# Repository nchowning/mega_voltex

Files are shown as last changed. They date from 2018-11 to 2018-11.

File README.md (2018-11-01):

# MEGA Voltex
An Arduino Mega 2560 Sound Voltex controller shield for use with [ACreal_IO](https://github.com/Nadeflore/ACreal_IO).

This is still SUPER early days. The plan is to solder components to this shield, desolder the USB connector & power connector from an Arduino Mega 2560, slap this bad boy on top of it, and design a 3D printed enclosure for it.

# Credit
- [mon's PocketVoltex](https://github.com/mon/PocketVoltex) - Rotary encoder footprint & model. mon has a ton of amazing projects and is a super nice guy!
- [kcswalter's Electronic CAD libraries](http://smisioto.no-ip.org/elettronica/kicad/kicad-en.htm) - Arduino Mega header. Lots of useful libraries, footprints, & models here!
- [KiCad's footprints](https://github.com/KiCad/kicad-footprints) - I modified a couple of their SW_Cherry MX1A footprints to add LED through-holes. I plan on submitting a PR upstream for this.

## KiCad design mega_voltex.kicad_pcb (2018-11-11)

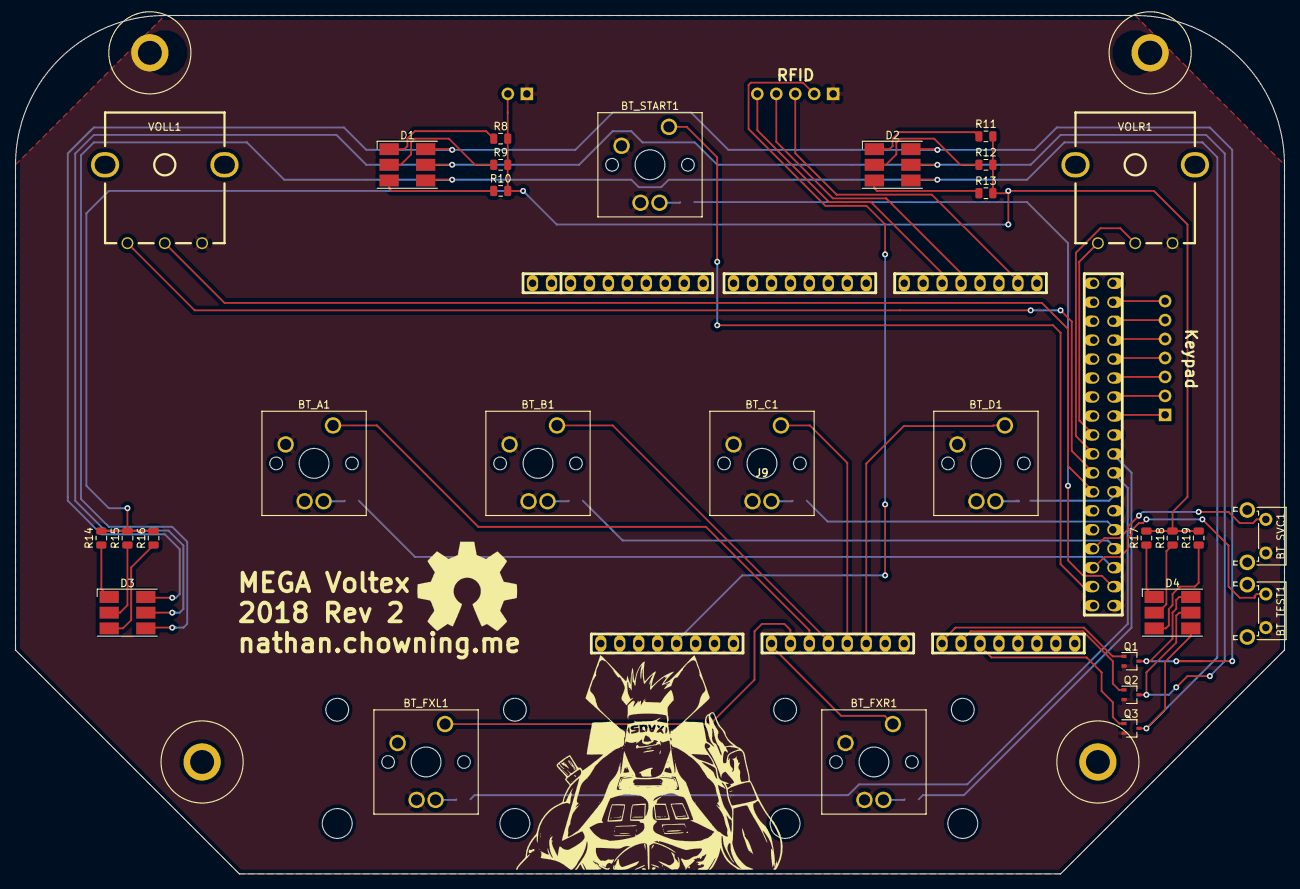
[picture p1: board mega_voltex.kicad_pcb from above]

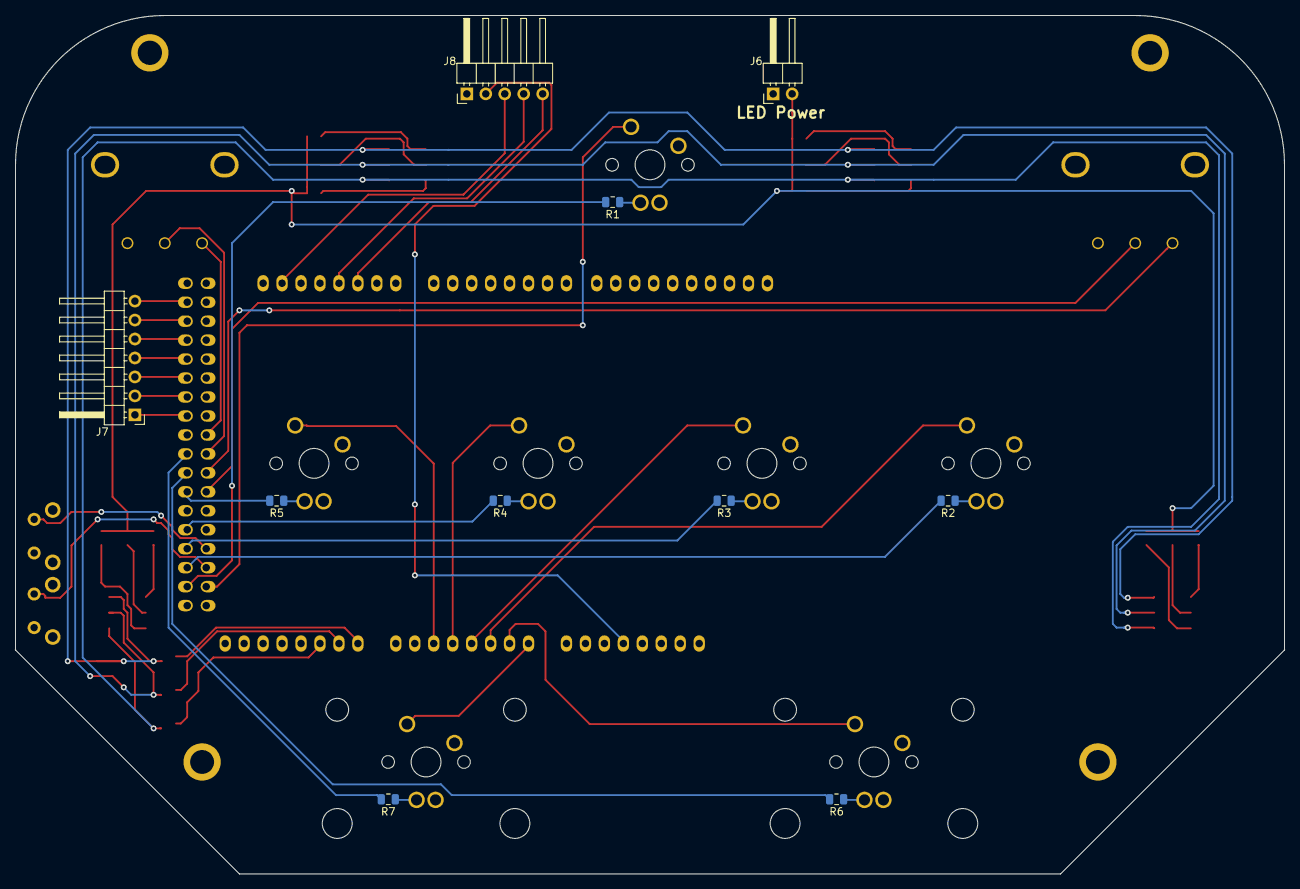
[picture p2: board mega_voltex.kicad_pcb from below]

Board: 2 copper layers, 170.0 x 115.0 mm, 44 parts (10 on the bottom side), 58 nets.

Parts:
BT_A1: SW_Push_LED; SW_Cherry_MX1A_1.00u_PCB
BT_B1: SW_Push_LED; SW_Cherry_MX1A_1.00u_PCB
BT_C1: SW_Push_LED; SW_Cherry_MX1A_1.00u_PCB
BT_D1: SW_Push_LED; SW_Cherry_MX1A_1.00u_PCB
BT_FXL1: SW_Push_LED; SW_Cherry_MX1A_2.00u_PCB
BT_FXR1: SW_Push_LED; SW_Cherry_MX1A_2.00u_PCB
BT_START1: SW_Push_LED; SW_Cherry_MX1A_1.00u_PCB
BT_SVC1: SW_Push; SW_Tactile_SPST_Angled_PTS645Vx58-2LFS
BT_TEST1: SW_Push; SW_Tactile_SPST_Angled_PTS645Vx58-2LFS
D1, D2, D3, D4: RGBLED_CREE_CLP6C; LED_RGB_Cree-PLCC-6_6x5mm_P2.1mm
J6: HEADER_2; PinHeader_1x02_P2.54mm_Horizontal
J7: HEADER_7; PinHeader_1x07_P2.54mm_Horizontal
J8: HEADER_5; PinHeader_1x05_P2.54mm_Horizontal
J9: Arduino_Mega_Header; arduino_mega_header
Mounting Hole: Banana_Jack_1Pin
Mounting Hole#2, Mounting Hole#3: Banana_Jack_1Pin
Q1, Q2, Q3: MMBT2222AWT1G; SOT-323_SC-70
R1, R2, R3, R4, R5, R6, R7, R8, R9, R10, R11, R12, R13, R14, R15, R16, R17, R18, R19: R_Small_US; R_0805_2012Metric
VOLL1: Rotary_Encoder; Encoder_Bourns_PEC16
VOLR1: Rotary_Encoder; Encoder_Bourns_PEC16

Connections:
5V: J8.2, J9.5
12V: J6.2, R8.2, R9.2, R10.2, R11.2, R12.2, R13.2, R14.2, R15.2, R16.2, R17.2, R18.2, R19.2
BT_A: BT_A1.1, J9.11
BT_B: BT_B1.1, J9.12
BT_C: BT_C1.1, J9.13
BT_D: BT_D1.1, J9.14
BT_FXL: BT_FXL1.1, J9.10
BT_FXR: BT_FXR1.1, J9.9
BT_START: BT_START1.1, J9.26
BT_SVC: BT_SVC1.1, J9.28
BT_TEST: BT_TEST1.1, J9.27
GND: BT_A1.2, BT_A1.3, BT_B1.2, BT_B1.3, BT_C1.2, BT_C1.3, BT_D1.2, BT_D1.3, BT_FXL1.2, BT_FXL1.3, BT_FXR1.2, BT_FXR1.3, BT_START1.2, BT_START1.3, BT_SVC1.2, BT_TEST1.2, J6.1, J8.1, J9.43, Q1.2, Q2.2, Q3.2, VOLL1.B, VOLR1.B
K1_1: J7.4, J9.56
K1_2: J7.3, J9.55
K1_3: J7.2, J9.54
K1_4: J7.1, J9.53
K1_A: J7.7, J9.59
K1_B: J7.6, J9.58
K1_C: J7.5, J9.57
LED6_B: D1.4, D2.4, D3.4, D4.4, Q3.3
LED6_G: D1.5, D2.5, D3.5, D4.5, Q2.3
LED6_R: D1.6, D2.6, D3.6, D4.6, Q1.3
LT_A: J9.45, R2.2
LT_B: J9.46, R3.2
LT_C: J9.47, R4.2
LT_D: J9.49, R5.2
LT_FXL: J9.50, R6.2
LT_FXR: J9.51, R7.2
LT_START: J9.44, R1.2
unnamed: BT_A1.4, R2.1
unnamed: BT_B1.4, R3.1
unnamed: BT_C1.4, R4.1
unnamed: BT_D1.4, R5.1
unnamed: BT_FXL1.4, R6.1
unnamed: BT_FXR1.4, R7.1
unnamed: BT_START1.4, R1.1
unnamed: D1.1, R8.1
unnamed: D1.2, R9.1
unnamed: D1.3, R10.1
unnamed: D2.1, R11.1
unnamed: D2.2, R12.1
unnamed: D2.3, R13.1
unnamed: D3.1, R14.1
unnamed: D3.2, R15.1
unnamed: D3.3, R16.1
unnamed: D4.1, R17.1
unnamed: D4.2, R18.1
unnamed: D4.3, R19.1
unnamed: J9.17, Q1.1
unnamed: J9.18, Q2.1
unnamed: J9.19, Q3.1
R1_DET: J8.3, J9.62
R1_RX: J8.4, J9.65
R1_TX: J8.5, J9.66
VOLL_A: J9.32, VOLL1.A
VOLL_B: J9.31, VOLL1.C
VOLR_A: J9.34, VOLR1.A
VOLR_B: J9.33, VOLR1.C

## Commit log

2018-11-01 Rearranged board, renamed module
    [mega_voltex.kicad_pcb, mega_voltex.sch]
2018-11-01 Added new footprints, updated schematic & PCB
    [mega_voltex.kicad_pcb, mega_voltex.sch]
2018-11-01 Added headers & resistors for LEDs
    [mega_voltex.kicad_pcb, mega_voltex.sch]
2018-11-01 Added library and changed reference to library
    [mega_voltex.sch]
2018-11-01 Forgot to save for headers
    [mega_voltex.sch]
2018-11-01 Lots of changes. PCB without LED1-5 headers is nearly complete
    [mega_voltex.kicad_pcb, mega_voltex.sch]
2018-11-09 Fixed some library/footprint difference issues with LEDs and transistors
    [mega_voltex.kicad_pcb, mega_voltex.sch]
2018-11-11 Added maxima silkscreen & moved top mounting holes
    [mega_voltex.kicad_pcb]
